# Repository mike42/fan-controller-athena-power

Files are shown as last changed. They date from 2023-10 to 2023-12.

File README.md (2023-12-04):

# PC Fan Controller for Athena Power Cases

This repository contains the circuit board and firmware for a fan controller which I designed to replace the splitter which ships with the Athena Power RM-1UC138 rackmount computer case.

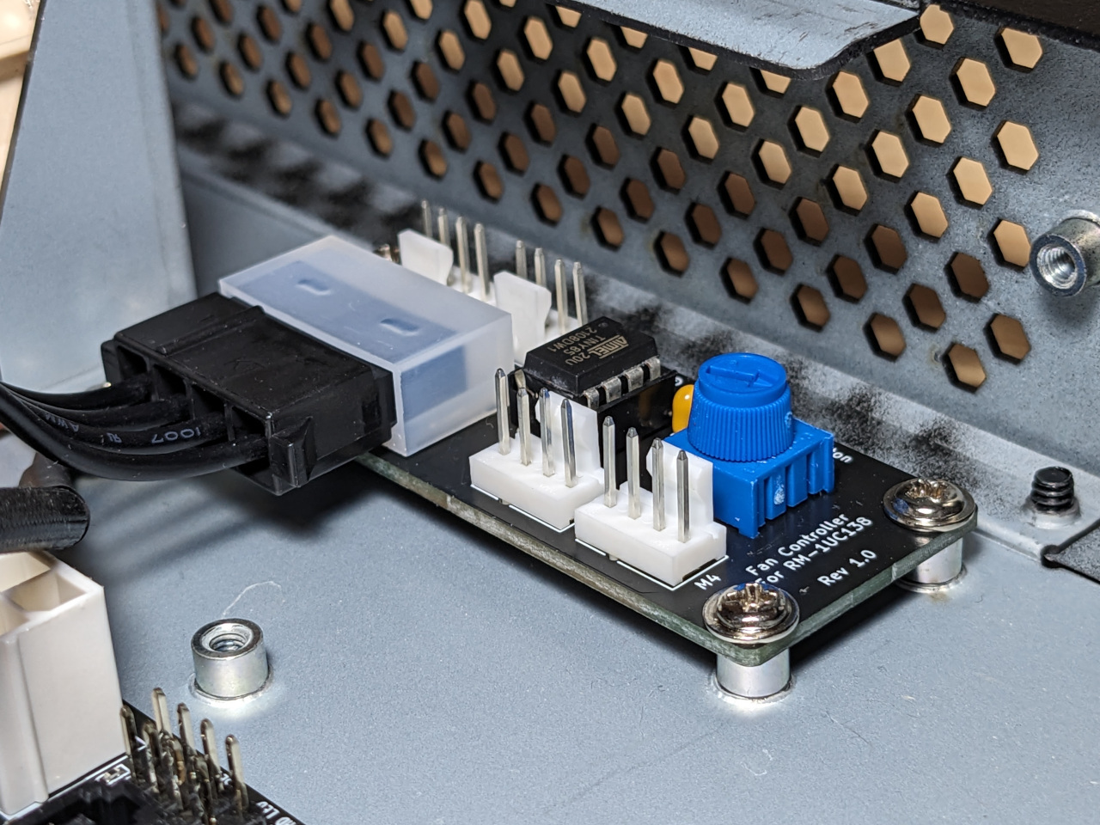
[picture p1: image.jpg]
Fan controller


Instead of running the bundled 12 V fans at full speed, this controller allows you to install your own PWM fans, and set a fixed speed via a potentiometer, with no involvement from the motherboard.

## Parts list

| Qty. | Description | Installed at | Product ref. |
|---|---|---|---|
| 1 | 0.1 µF ceramic capacitor | C1 | [Adafruit 753](https://www.adafruit.com/product/753) |
| 1 | PC power "Molex" connector | J1 | [Sparkfun PRT-15700](https://www.sparkfun.com/products/15700) |
| 4 | 4-pin PC fan header | M1, M2, M3, M4 | [Molex 47053-1000](https://au.mouser.com/ProductDetail/Molex/47053-1000) |
| 1 | 10 kΩ Potentiometer 0.1" spacing | RV1 | [Core Electronics CE09096](https://core-electronics.com.au/breadboard-compatible-potentiometer-10k-ohm.html) |
| 1 | ATtiny85 microcontroller | U1 | [ATtiny85-20P](https://au.mouser.com/ProductDetail/Microchip-Technology/ATTINY85-20PU) |
| 1 | Optional: DIP-8 socket | U1 | [TE 1-2199298-2](https://au.mouser.com/ProductDetail/TE-Connectivity/1-2199298-2) |

## More info

- [Controlling computer fans with a microcontroller](https://mike42.me/blog/2023-09-controlling-computer-fans-with-a-microcontroller) - which shows the use of a TL-866II+ to program the ATtiny85.
- [Building a 1U quiet NAS](https://mike42.me/blog/2023-10-building-a-1u-quiet-nas) - information about the computer build which this project was created for.

## Licensing 

While you are free to use these files to build this project yourself, you do so at your own risk. No warranty or support is offered.

The code for the ATTINY85 microcontroller is based on "[4-Wire-FAN-Arduino](https://github.com/marceloaqno/4-Wire-FAN-Arduino/blob/master/ATtiny_PWM_Phase_Corret_25kHz.ino)" by Marcelo Aquino, which is licensed under the GNU GPL.

The hardware files in this repository are additionally licensed under the [Creative Commons Attribution 4.0 International License](https://creativecommons.org/licenses/by/4.0/).

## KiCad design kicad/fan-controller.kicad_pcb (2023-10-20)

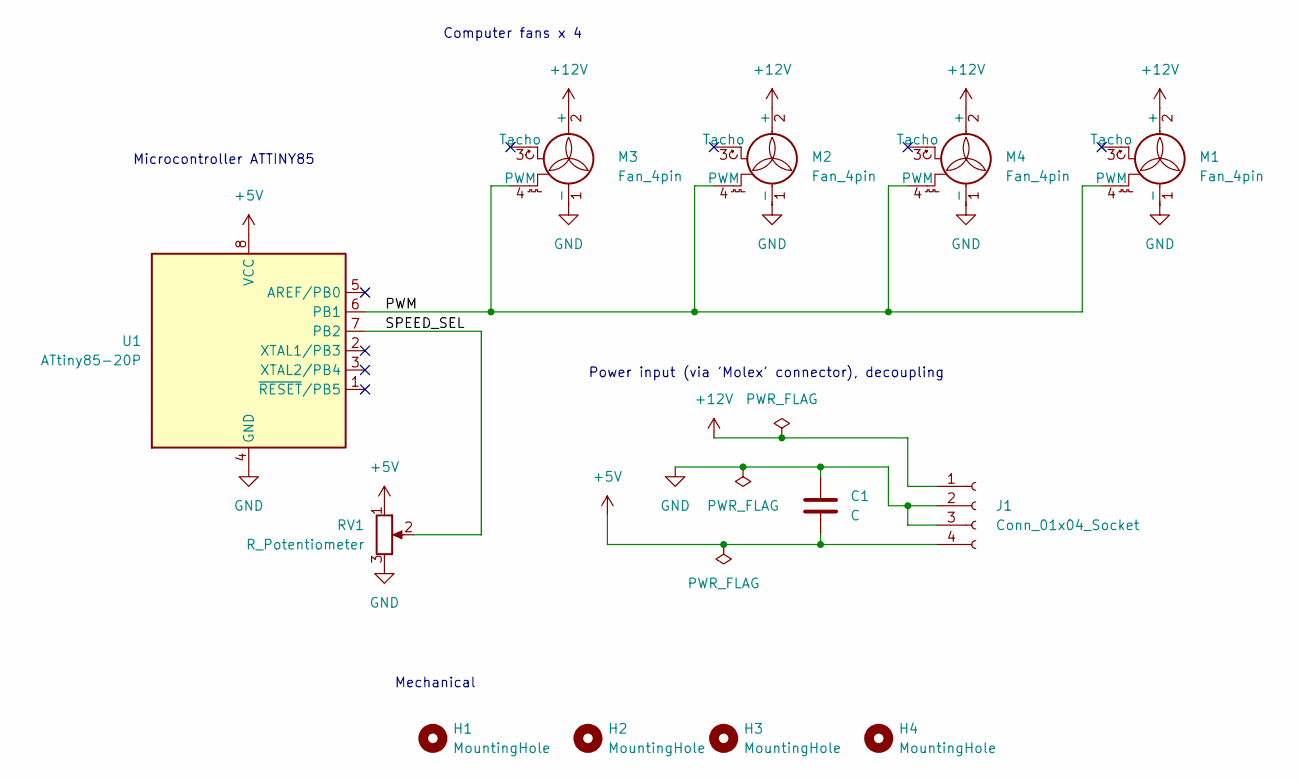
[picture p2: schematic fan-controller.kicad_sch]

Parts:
C1: C; C_Disc_D3.0mm_W2.0mm_P2.50mm
H1, H2, H3, H4: MountingHole; MountingHole_3.5mm
J1: Conn_01x04_Socket; PC_Molex_Power
M1, M2, M3, M4: Fan_4pin; FanPinHeader_1x04_P2.54mm_Vertical
RV1: R_Potentiometer; PinHeader_1x03_P2.54mm_Vertical
U1: ATtiny85-20P; DIP-8_W7.62mm

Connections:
+5V: C1.2, J1.4, RV1.1, U1.8 (VCC)
+12V: J1.1, M1.2 (+), M2.2 (+), M3.2 (+), M4.2 (+)
/PWM: M1.4 (PWM), M2.4 (PWM), M3.4 (PWM), M4.4 (PWM), U1.6 (PB1)
/SPEED_SEL: RV1.2, U1.7 (PB2)
GND: C1.1, J1.2, J1.3, M1.1 (-), M2.1 (-), M3.1 (-), M4.1 (-), RV1.3, U1.4 (GND)

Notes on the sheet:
Mechanical
Microcontroller ATTINY85
Computer fans x 4
Power input (via 'Molex' connector), decoupling

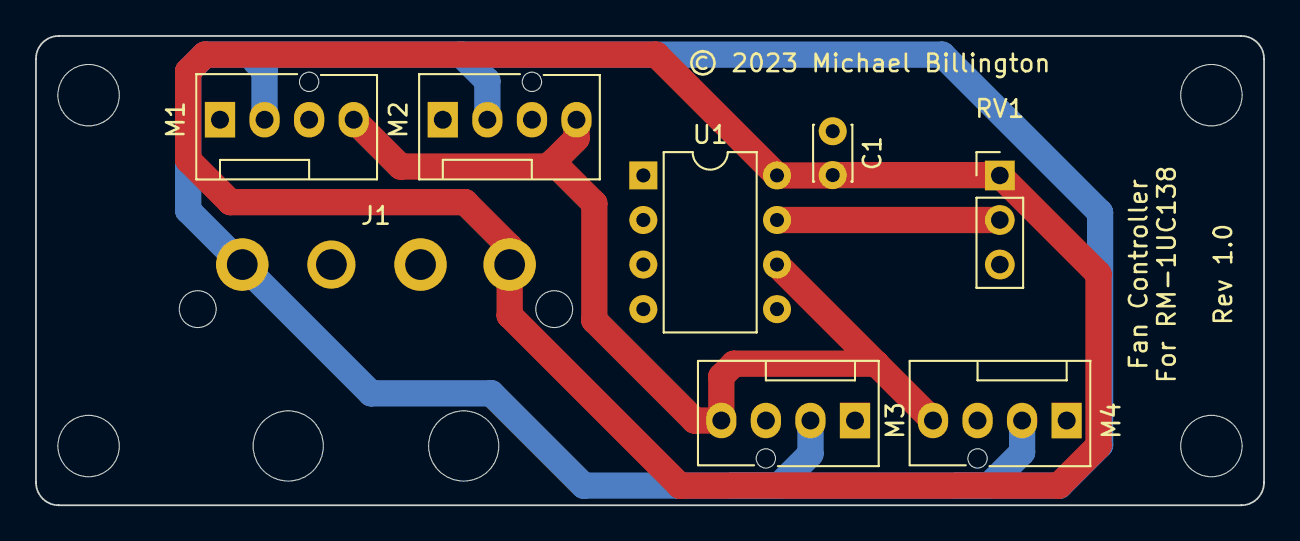
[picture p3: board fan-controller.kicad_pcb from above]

Board: 2 copper layers, 70.0 x 26.8 mm, 12 parts (0 on the bottom side), 5 nets.

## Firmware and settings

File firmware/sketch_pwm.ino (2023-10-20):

/*
 *                         ATtiny85
 *                      -------u-------
 *  RST - A0 - (D 5) --| 1 PB5   VCC 8 |-- +5V
 *                     |               |
 *        A3 - (D 3) --| 2 PB3   PB2 7 |-- (D 2) - A1  --> 10K Potentiometer
 *                     |               | 
 *        A2 - (D 4) --| 3 PB4   PB1 6 |-- (D 1) - PWM --> Fan Blue wire
 *                     |               |      
 *              Gnd ---| 4 GND   PB0 5 |-- (D 0) - PWM --> Disabled
 *                     -----------------
 */
 
// normal delay() won't work anymore because we are changing Timer1 behavior
// Adds delay_ms and delay_us functions
#include <util/delay.h>    // Adds delay_ms and delay_us functions

// Clock at 8mHz
#define F_CPU 8000000  // This is used by delay.h library

const int PWMPin = 1;  // Only works with Pin 1(PB1)
const int PotPin = A1;

void setup()
{
  pinMode(PWMPin, OUTPUT);
  // Phase Correct PWM Mode, no Prescaler
  // PWM on Pin 1(PB1), Pin 0(PB0) disabled
  // 8Mhz / 160 / 2 = 25Khz
  TCCR0A = _BV(COM0B1) | _BV(WGM00);
  TCCR0B = _BV(WGM02) | _BV(CS00); 
  // Set TOP and initialize duty cycle to 50%
  OCR0A = 160;  // TOP - DO NOT CHANGE, SETS PWM PULSE RATE
  OCR0B = 80; // duty cycle for Pin 1(PB1)
  // initial bring-up: leave at 50% for 4 seconds
  _delay_ms(4000);
}

void loop()
{
  int in, out;
  // follow potentiometer-set speed from there
  in = analogRead(PotPin);
  out = map(in, 0, 1023, 0, 160);
  OCR0B = out;
  _delay_ms(200);
}

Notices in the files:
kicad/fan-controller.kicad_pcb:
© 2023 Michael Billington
